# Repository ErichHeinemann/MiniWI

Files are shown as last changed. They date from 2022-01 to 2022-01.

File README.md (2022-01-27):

# MiniWI Fork with ESP32 and BLE ( Midi over Bluetooth )
MIDI woodwind controller

2022-01-27 E.Heinemann Use the folder for the MINI-WI-ESP32 Version to get a wireleess version which plays via Bluetooth BLE
Links to Youtube: https://www.youtube.com/embed/_GEmQJgfbyA

2016-04-17

This MIDI controller is running on an Arduino Pro Mini with Atmega328 16MHz/5V. It makes use of breakouts for analog pins A6 and A7, so it needs a Pro Mini version with these breakouts. The pressure sensor used for the project is the Freescale MPX5010GP. Fingering is reverse engineered from Akai EWI and note values are calculated from pressed keys. For details on this, read my guest post on the Gordophone blog. 

http://gordophone.blogspot.se/2016/04/guest-post-alternative-way-of-note.html

Details on the state machine approach for handling the events is also available on Gordon's blog where I borrowed it from. He's got a step-by-step how-to on DIY wind controllers that I highly recommend.

http://gordophone.blogspot.se/2013/01/a-series-basics-of-diy-wind-controllers.html

Hardware notes for connection of MIDI, pressure sensor, keys and joysticks are available in the MiniWI.ino file.

The MIDI routines and the MIDI connections are pretty standard, but I first found them on the midikits.net website, so I'll give Tom Scarff a mention here. Kept his nice MIDI pinout ASCII sketch thing and some comment style too. 

The controller is made to work well with synthesizers using wind controller patches from Patchman Music, with the breath data sent by CC #2 (Breath). For testing I’ve been using their wind controller soundbank for Roland JV-1010.

http://www.patchmanmusic.com

Or you can make your own patches optimized for breath control. Pointers for doing that can also be found on the Patchman website.

Questions and suggestions are welcome. Just send them to johan@helgo.net.

-Johan Berglund

2016-05-17

Variations:

MiniWI.ino is the original proof of concept breadboard version with regular switches.

MiniWI-lite.ino is a simplified version (no joysticks) for my guest post on the Gordophone blog.

MiniWI-cap.ino is the capacitive touch version implemented in my first playable prototype.

MiniWI-cap-pmt.ino is a modification of the touch version to feature portamento (glide) control and a separate potentiometer for setting base octave instead of using sideways motion of joystick to increase range. This reduces instantly playable range but increases the total range of the controller.

MiniVI-cap.ino is a not yet realized EVI version (Electronic Valve Instrument) based on the Akai EVI1000 and the Steiner MIDI EVI.

2016-05-22

I’ve added some pictures from my Instagram account. Check it out for more pictures from this and my other projects.

https://www.instagram.com/trasselfrisyr/

2016-05-30

Project profile for the MiniWI added on Hackaday.io

https://hackaday.io/project/11843-miniwi-woodwind-midi-controller

2016-06-03

Added optional Casio DH 2nd octave fingerings. Default disabled. Set #define casioMod 1 to set default enabled. Hold octave stick up at power on for manual selection of the setting that is not default.

2016-06-12

Added tested and working version of the new TeensieWI, a simplified version for USB MIDI using the built in capacitive touch sensing in the Teensy LC and breath sensing from the MPX5010GP. Small warning here: the breath sensor output is not limited and could reach values near 5V, while the analog input on the Teensy LC is 3.3V and not rated 5V safe. To reach these levels you’d have to blow really, really hard. If you need to feel safe, go with a Teensy 3.1 or 3.2 as they have 5V tolerant inputs. Only minor alterations needed in the code for use with Teensy 3.x (touch sensing on other pins, some as pads on the back).

2017-10-31

Improved the joystick version of the TeensieWI, now called T.WI, with breath response curves and some other stuff that can be configured at plug-in. Started making these for sale on Tindie. https://www.tindie.com/products/yoe/twi-a-teensy-based-usb-midi-woodwind-controller/

2022-01-03 E.Heinemann
#MINI WI ESP32
I am trying to build this Wind-Instrument but I changed the MCU from Aarduino to ESP32, still using a MPR121, MIDI via Blutooth, ADS115 as diffrential ADC for DP53-Pressuresensor

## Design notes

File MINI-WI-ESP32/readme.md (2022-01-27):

# MINI WI ESP32

I replaced the Arduino by an ESP32, still use an MPR121 via I2C ( GPIO-5 for SDA, GPIO-23 for SCL ) and an ADS1115 to get the differential pressure related voltage.
While COVID and the "Chip-Missing" - Pandemic, I bought 2 (bad or worse) DP53DP which are Differential Pressure Mesurement Sensors which need 2 ADC-inputs on the ADS1115.

Video ( german ) https://www.youtube.com/watch?v=_GEmQJgfbyA
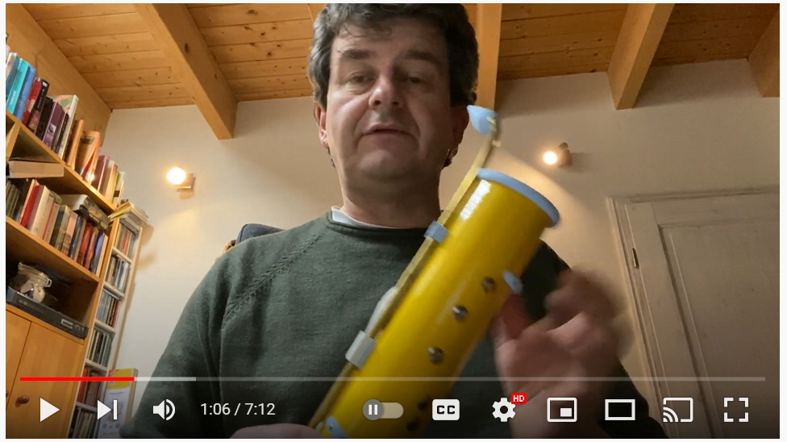
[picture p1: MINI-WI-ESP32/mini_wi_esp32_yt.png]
Youtube (https://www.youtube.com/watch?v=_GEmQJgfbyA "Mini WI Windinstrument on Youtube (german)")


As I had already bad experience with the ADC of the ESP, I tried to use a ADS115 and would add a MPU6050 later in the sketch to send MIDI-CC-Messages.

I don´t want to support a physical MIDI-Out, - to clunky wires and I did think of an internal battery but prefer an external USB-Powerbank which I could use for dirrent purposes ... I mainly play guitar, not MINI-WI. I did not implement the Joysticks in the code yet because I wanted to use the fingering of a normal recorder and I didn´t had Joysticks laying around. ( update - got Joystick )

Basically, I am a guitar-player and not a flute or sax-player. In school, we all had to learn to play the recorder and so, I tried to change the fingering to be the same like for a recorder.
I moved one touch-sensor to the back, used 2 sensors for the left hand pinky and 2 for the right pinky finger and one sensor (RH6) for the thumb of the right hand. 
Currently the right-hand thumb (RH6), switches to a lower octave.

For the body of the Mini-WI I used this material:
- an old inner cardboard role/pipe r=3.1cm by 40cm , 
- pimped it up with adhesive film ( one in gold and one in orange )
- thinnest brass-tube (1 meter ) from the hardwarestore ( around 3mm diameter )
- Silicon-Tube ( 50cm ) ( aquarium accessories )
- 12 cheap brass (looking) upholstery nails from hardwarestore ( 1cm diameter )
- thin isolated wire
- some sticky tape to manage the wires

I added a OpenSCAD-File which I used to create different 3D-printed parts like rings for the:
- fingerholes, - finally not used
- mouthpiece(s) , - a thin version and a wider version 
- top and bottom to cover the holes of the tube
- a holder to be able to mount the pressure-sensor from the outside

There was no need to cut the cardboard-role from top to bottom! 

Step 1:
Cut the cardboard-role to Your prefered length ( use Your hands to get a good length and don´t forget the reserved place/area for the ESP32 and other modules, hold it like a flute and find the length which looks good. )

Step 2: ( optional )
Wrap the adhesive film around it, leave top and bottom open

Step 3: 
Find the best places for the captive sensors. Hold the pipe like You would hold it for playing it as a flute or oboe etc.
Mark the position of Your fingers. Keep in mind, the pinkys will get 2 sensors, don´t spread Your pinky to much to reach out to the second hole.
As the sensors are captive sensors, there has to be enough space between the fingers and sensors.
Sensors for the left pinkys should be wider, for the right-hand pinkys it should be more narrow to be able to get both with the pinky at once.

Step 4:
Press the brass-Nails a bit into the cardboard-pipe to create simple holes.

Step 5:
Find a good position ( in my case on the right-side ) where You would like to inlay the pressure-sensor into the pipe.
Print out or build Your own holder for the pressure sensor. Take mesasurement and cur out an rectangle to push the sensor to the inside of the box. 
I have used a fresh sharp box cutter and a lot of respect.

Step 6:
print out the mouthpiece, bend the brass-tube to let it look like to upper part of a sax.
cut it  to let match the length of the mini-wi from mouthpiece down to the bottom! - full length!
Print out the Split-Box and some Pipe-Holders.

Step 7:
Do a second cut of the Brass-Pipe some centimeters below the pressure sensor where You have to install the Split-Box.
The Splitbox splits the air, comming from the mouthpieces and pressing it back upwords to the pressure-sensor which is facing downwards. 
.. any spit will flow downwards into the second brass pipe to the bottom.
Only Your feet will get wet after a long jam-session, - not Your fingers.
use 2 or more pipeholders to fix the brass-pipe onto the cardboard-pipe.

Step 8:
Solder thin isolated wire to the tip of the (12) brass-nails and loop the wire to the inside of the pipe. 
The wires should all fall down to the bottom of Your mini-wi.
Start with the highest Wire ( High c hole )

Step 9:
Print out the Bottom and later the Top to cover the Cardboard-Pipe.
I have tried to design two versions for the bottom. 
a) the USB faces straigt downwards ... Your have to lay down the instrument to the side if You pause Your jam-session
b) the USB faces backwards to You and You get a flat bottom, - Instrument could stand on the bottom.

Step 10:
use some Breadbaord/Stripboard which has a size of around 8 x 4cm to hold the modules:
MPR121, ADS1115 and ESP32 or only MPR121 and ADS1115 ( depends on the bottom-version a) or b) ) 
Use sockets for the modules or not, it is up to You.

Step 11:
Solder all modules ( depends on version of bottom ) to the Stripboards

Step 12:
Create the connection for VCC/VDD 3.3Volts, GND, SDA and SCL between all modules.
Connect the Wires from the brass-nails ( Touch Sensors ) from Bottom Down to the 12 Inputs 0 to 11 of the MPR121 module.

Step 13: 
Insert the MPX DP53DP (Pressure-Sensor ) via the silicon-tube to the Split-Box.
solder 4 wires to the DP52DP ( V+ goes to 3.3V or 5 Volts ...  I had measured very low voltages and decided to go to 5 Volts.
Out + / Out - have to be connected to the ADS1115 ADC0 and ADC1.
Check the documentation for YOUR pressure-seensor as I did not find a genral pinout of theem. they are different from modell to model!

Step 14:
Measure the connections to the ESP32 with a multimeter, - are there any shorts between SDA/SCL or +VDD and GND??
Check the Connection from the Touch-Sensors to the MPR121

Step 15:
Check the airpressure, - blow into the mouthpiece and check for any leakages. Air and spit should come out at the end of the brass-pipe at the bottom of the mini-wi.

Step 15:
Perhaps You have to install all the needed librarys or the Arduino IDE.
Upload the Core to the ESP32 ( perhaps You have to press "BOOT" to get it) 
I have used the Adafruit-Libraries for ADS1115 and the MPR121 and finally the "ESP32 BLE MIDI" - Library

Step 16:
Start an App on Your Smartphone which support MIDI BLE. 
Power up the Mini-WI, after the LED flashes stopps, blow into the moutpiece and press some brass-nails.

Step 17:
optimize it Your way, add Joysticks, more Touch-Sensors to the ESP32. 
Implement Your funktion when RH6 is pressed or Joysticks are moved.

There are a lot videos which explain how to connect a BLE - MIDI-Controller to Your Smartphone or PC.

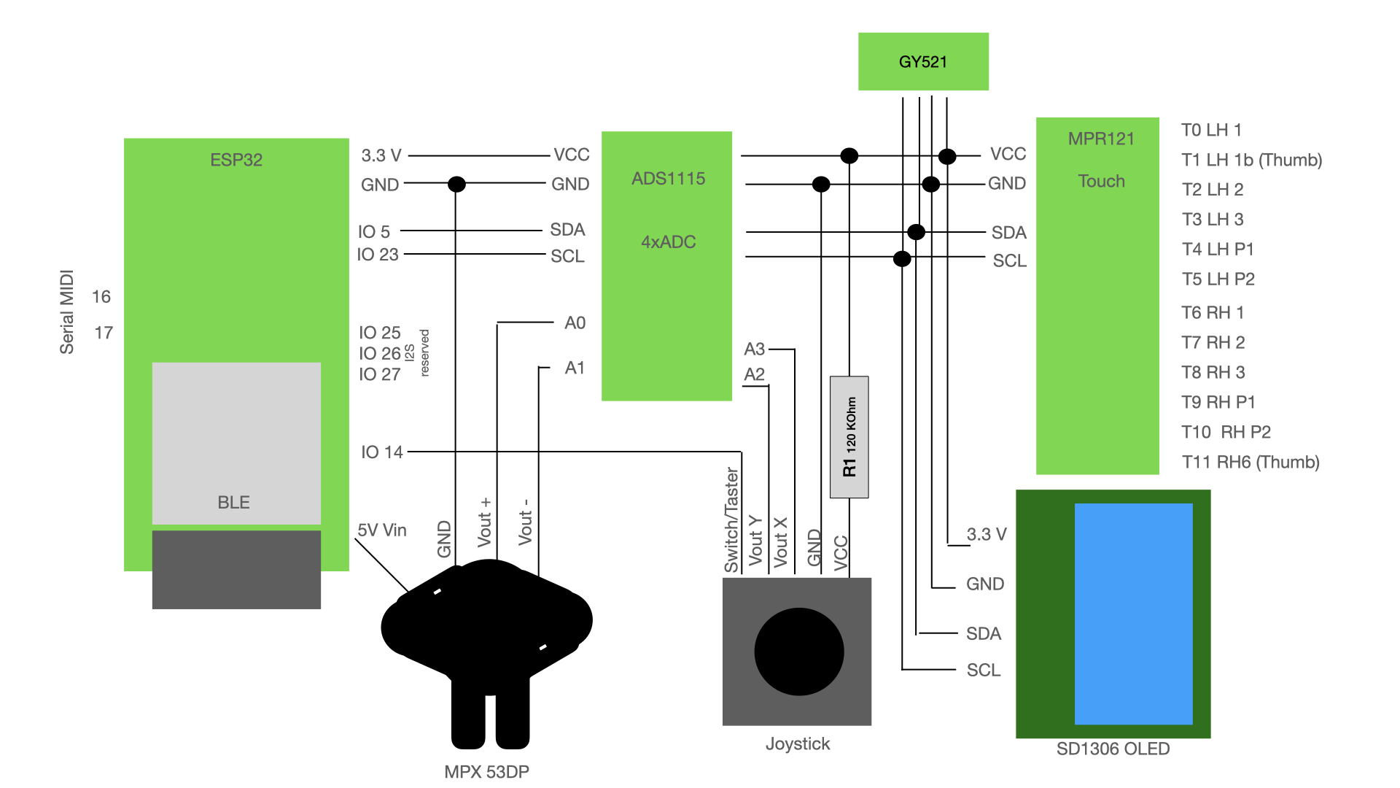
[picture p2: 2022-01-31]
MINI-WI-ESP32/MINI_WI_Schematic.001.png

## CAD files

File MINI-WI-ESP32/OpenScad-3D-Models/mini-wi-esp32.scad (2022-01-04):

// At the end, there are a lot of disabled statements
// active as amany as You need

// OpenSource GPL 

// E.Heinemann 2022

radPipe = 50; // 10cm
radRing = 6;


$fs = 0.15;
$fn = 50;
/*
color ("Red") rotate([180,0,0])linear_extrude(height=2) { scale([0.1,0.1])
import(file = "milbesos.svg", center = true, dpi = 96);
}
rotate([0,0,0])linear_extrude(height=5,convexity=2) { scale([0.45,0.45])
import(file = "milbesos.svg", center = false, dpi = 96);
}
*/

module roundedcube(size = [1, 1, 1], center = false, radius = 0.5, apply_to = "all") {
	// If single value, convert to [x, y, z] vector
	size = (size[0] == undef) ? [size, size, size] : size;

	translate_min = radius;
	translate_xmax = size[0] - radius;
	translate_ymax = size[1] - radius;
	translate_zmax = size[2] - radius;

	diameter = radius * 2;

	obj_translate = (center == false) ?
		[0, 0, 0] : [
			-(size[0] / 2),
			-(size[1] / 2),
			-(size[2] / 2)
		];

	translate(v = obj_translate) {
		hull() {
			for (translate_x = [translate_min, translate_xmax]) {
				x_at = (translate_x == translate_min) ? "min" : "max";
				for (translate_y = [translate_min, translate_ymax]) {
					y_at = (translate_y == translate_min) ? "min" : "max";
					for (translate_z = [translate_min, translate_zmax]) {
						z_at = (translate_z == translate_min) ? "min" : "max";

						translate(v = [translate_x, translate_y, translate_z])
						if (
							(apply_to == "all") ||
							(apply_to == "xmin" && x_at == "min") || (apply_to == "xmax" && x_at == "max") ||
							(apply_to == "ymin" && y_at == "min") || (apply_to == "ymax" && y_at == "max") ||
							(apply_to == "zmin" && z_at == "min") || (apply_to == "zmax" && z_at == "max")
						) {
							sphere(r = radius);
						} else {
							rotate = 
								(apply_to == "xmin" || apply_to == "xmax" || apply_to == "x") ? [0, 90, 0] : (
								(apply_to == "ymin" || apply_to == "ymax" || apply_to == "y") ? [90, 90, 0] :
								[0, 0, 0]
							);
							rotate(a = rotate)
							cylinder(h = diameter, r = radius, center = true);
						}
					}
				}
			}
		}
	}
}

module ring(
        h=1,
        od = 10,
        id = 5,
        de = 0.1
        ) 
{
    difference() {
        cylinder(h=h, r=od/2);
        translate([0, 0, -de])
            cylinder(h=h+2*de, r=id/2);
    }
}


// ring(2, 16, 12, 0.1 );

module torus2(r1, r2)
{
rotate_extrude() translate([r1,0,0]) circle(r2);
}

module oval_torus(inner_radius, thickness=[0, 0])
{
rotate_extrude() translate([inner_radius+thickness[0]/2,0,0]) ellipse(width=thickness[0], height=thickness[1]);
}


module fingerhole( rFinger = 8, rPipe = 50 ){
    difference(){
      union(){  
        torus2( rFinger, 1.1 );
        difference(){  
            color([0,1,0]) rotate([0,-90,0]) translate([ -(rPipe/2 + rFinger*1),0,0 ]) torus2(rPipe/2,  rFinger *1.3 );
             cylinder( rFinger*2.5, rFinger, rFinger, center=true);
        }
      }    
      union(){
        //translate ([0,0,0.5 ]) ring(1, (rFinger*2)-2, (rFinger*2)-4, 0.1 );
        translate ([0,0,0.5 ]) cylinder(1, 5, 5 );
        rotate([0,-90,0]) translate([ -rPipe,0,-0 ]) color([1,0,0]) cylinder( rFinger*4, rPipe, rPipe, center=true);
          
      }
    }
}


module fingerpinch( rFinger = 8, lPinch=16, wPinch=8, r1=30, r2=30, rPipe = 50 ){
    
    difference(){
      union(){  
        // translate([  0, lPinch/3/2+rFinger ,0 ]) roundedcube([ wPinch, lPinch /3 , 4 ], center=true, 0.5);  
          difference(){
              union(){
                          torus2( rFinger, 2 );
        rotate( [0,0,-r1] ) translate([  0, lPinch/2+rFinger ,0 ]) 
              roundedcube([ wPinch, lPinch, 4 ], center=true, 0.5);
              }      
        rotate( [0,0,-r1] ) translate([  0, lPinch/2+rFinger ,0 ]) 
              translate([ 0, 3 ,2 ]) cube([ 2, lPinch*1.5, 2 ], center=true);  
         }

        difference(){  
            color([0,1,0]) rotate([0,-90,0]) translate([ -(rPipe/2+ rFinger),2,-0 ]) torus2(rPipe/2,  rFinger *1.3 );
             cylinder( rFinger*2.5, rFinger, rFinger, center=true);
        }
      }    
      union(){
  
          
        translate ([0,0,0.5 ]) ring(1, (rFinger*2)-2, (rFinger*2)-4, 0.1 );
        rotate([0,-90,0]) translate([ -rPipe,0,-0 ]) color([1,0,0]) cylinder( rFinger*4, rPipe, rPipe, center=true);
          
      }
    }
}

module dualfingerhole( rFinger1 = 8, rFinger2=7, rPipe = 50 ){
    difference(){
      union(){  
        translate ([rFinger1+0.5,0,0 ])  torus2( rFinger1, 2 );
        translate ([-rFinger2-0.5,0,0 ])  torus2( rFinger2, 2 );
          
        difference(){  
           color([0,1,1]) rotate([0,-90,0]) translate([ -(rPipe/2+ rFinger1),2,-0 ]) torus2(rPipe/2,  rFinger1 *1.3 );
            union(){
             translate ([rFinger1+0.5,0,0 ]) cylinder( rFinger1*2.5, rFinger1, rFinger1, center=true);
             translate ([-rFinger2-0.5,0,0 ])cylinder( rFinger2*2.5, rFinger2, rFinger2, center=true);
        }
        }
      }    
      union(){
        translate ([rFinger1+0.5,0,0.5 ]) ring(1, (rFinger1*2)-2, (rFinger1*2)-4, 0.1 );
        translate ([-rFinger2-0.5,0,0.5 ]) ring(1, (rFinger2*2)-2, (rFinger2*2)-4, 0.1 );

        rotate([0,-90,0]) translate([ -rPipe,0,-0 ]) color([1,1,0]) cylinder( (rFinger1+rFinger2)*4, rPipe, rPipe, center=true);
          
      }
    }
}


module dualsidefingerhole( rFinger1 = 8, rFinger2=7, rotFinger1=1, rotFinger2=5, rPipe = 50 ){
    difference(){
      union(){  
        rotate([-rotFinger1,0,0]) translate ([0,rFinger1+1,0 ])  torus2( rFinger1, 2 );
        rotate([rotFinger2,0,0]) translate ([0,-rFinger2,0 ])  torus2( rFinger2, 2 );
          
        difference(){  
            color([0,1,1]) rotate([0,-90,0]) translate([ -(rPipe/2+ rFinger1),2,-0 ]) torus2(rPipe/2,  rFinger1 *1.3 );
            union(){
             rotate([- rotFinger1,0,0]) translate ([0, rFinger1+1,0 ]) cylinder( rFinger1*2.5, rFinger1, rFinger1, center=true);
             rotate([rotFinger2,0,0])  translate ([0,-rFinger2,0 ])cylinder( rFinger2*2.5, rFinger2, rFinger2, center=true);
        }
        }
      }    
      union(){
       rotate([- rotFinger1,0,0]) translate ( [0,rFinger1+1,0.5 ]) ring( 1, (rFinger1*2)-2, (rFinger1*2)-4, 0.1 );
       rotate([rotFinger2,0,0]) translate ([0,-rFinger2,0.5 ]) ring( 1, (rFinger2*2)-2, (rFinger2*2)-4, 0.1 );

        rotate([0,-90,0]) translate([ -rPipe,0,-0 ]) color([1,1,0]) cylinder( (rFinger1+rFinger2)*4, rPipe, rPipe, center=true);
          
      }
    }
}

module mouthpiece( w1=8, w2=10, h1=50 , h2=8, dr=3 ){
    // dr = durchmesser der Tube 
  difference(){
    hull(){
      translate([0,0,h1/10])cylinder( w1,w2,w2 ); 
      color([1,1,0]) translate([0,- w1/3,0])cylinder( 10,dr+1,dr+1 );   
      //translate([0,0,h1/2 + 2]) cube( [w2,w2,h1/2] , center=true); 
      translate([0,-w2/4,h1/2 + 2]) roundedcube( [w2,w2/2,h1] , center=true , 0.5); 
               
    }
    
    union(){
   rotate([0,-90,0]) translate([ h1,h1,-0 ]) color([1,1,0]) cylinder( (w1+w2), h1, h1, center=true );
        hull(){
       translate([0,-w2/4,h1])cube( [w2/1.5,w2/4,h1/2] , center=true );        
     // the hole for the pipe to the body
      color([1,1,0]) translate([0,- w1/3,0])cylinder( h1/2,dr,dr );   
        }
        
    }
  }
}

module mouthpieceWide( w1=8, w2=18, h1=50 , h2=8, dr=3 ){
    // dr = durchmesser der Tube 
  difference(){
    hull(){
      translate([0,0,h1/10])cylinder( w1,w2/1.8,w2/1.8 ); 
      color([1,1,0]) translate([0,- w1/3,0])cylinder( 10,dr+1,dr+1 );   
      //translate([0,0,h1/2 + 2]) cube( [w2,w2,h1/2] , center=true); 
      translate([0,-w2/4,h1/2 + 10]) roundedcube( [w2*1.1,w2/5,h1-5] , center=true , 0.5); 
               
    }
    
    union(){
        
        // Testschnitt: translate([0,-10,-5]) cube([100,100,100]);
        rotate([0,-90,0]) translate([ h1-4,h1+1.5,-0 ]) cylinder( (w1+w2), h1+1, h1+1, center=true );
        hull(){
            translate([0,-w2/4,h1])cube( [w2/1.5,w2/16,h1/2] , center=true );        
            // the hole for the pipe to the body
            color([1,1,0]) translate([0,- w1/3,0])cylinder( h1/2,dr,dr );   
        }
        
    }
  }
}


module pipeflansch( dr=3.55, rPipe=29.5 ){
    difference(){
      union(){  
        //#torus2( dr, 2 );
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

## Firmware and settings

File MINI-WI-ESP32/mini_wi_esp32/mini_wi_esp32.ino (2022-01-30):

#include <Arduino.h>

// #define MIDI5Pin

// ESP32_BLE_MIDI https://github.com/max22-/ESP32-BLE-MIDI
#define ESP32_BLE_MIDI

#ifdef ESP32_BLE_MIDI
#include <BLEMidi.h>
#endif

// #define PitchbendTouch
#define PitchbendAnalog

// #define ModulationGyro
#define ModulationAnalog
#define ModulationPortamentoCombi


/*
 * 
 * // https://github.com/lathoub/Arduino-BLE-MIDI
#include <BLEMIDI_Transport.h>

// #include <hardware/BLEMIDI_ESP32_NimBLE.h>
#include <hardware/BLEMIDI_ESP32.h>
// #include <hardware/BLEMIDI_nRF52.h>
// #include <hardware/BLEMIDI_ArduinoBLE.h>

// BLEMIDI_CREATE_DEFAULT_INSTANCE()
BLEMIDI_CREATE_INSTANCE( "MIDI MINI WI", MIDI )
// 9c:9c:1f:e2:19:d2
*/

unsigned long t0 = millis();
bool isConnected = false;

uint8_t modus = 0; // 0 = Play-Mode 1= Menu

// GPIO 14, Touch6 as extra Touchpin used directly on ESP32
uint8_t touchpin = 14; // touchpin_val= touchRead( touchpin ); 
uint16_t touchPin_Value=0; // Value of readed touchpin
uint16_t touchPin_Value_Max = 70; // has to be evaluated
uint16_t touchPin_last_Value=0;
uint8_t touchPin_Value_midi=0;
uint8_t velocity_min = 50;
// #include "FS.h"
// #include <LITTLEFS.h>

#include <WiFi.h>

// #include <MIDI.h>
#define NORM127MUL  0.007874f

// #define MIDIRX_PIN 16
// #define MIDITX_PIN 17

  uint16_t touchValue = 0;
  uint16_t lastTouchValue = 0;

// struct Serial2MIDISettings : public midi::DefaultSettings{
//   static const long BaudRate = 31250;
//   static const int8_t RxPin  = MIDIRX_PIN;
//   static const int8_t TxPin  = MIDITX_PIN; // LED-Pin
// };

// HardwareSerial MIDISerial(2);
// MIDI_CREATE_CUSTOM_INSTANCE( HardwareSerial, MIDISerial, MIDI, Serial2MIDISettings );


//I2C
#include <SPI.h>
#include <Wire.h>

// Display
// #include <Adafruit_GFX.h>
// #include <Adafruit_SSD1306.h>

// MPR121
#include <Adafruit_MPR121.h>

// ADS1115
#include <Adafruit_ADS1X15.h>

// Adafruit_ADS1115 ads;  /* Use this for the 16-bit version */
Adafruit_ADS1015 ads;     /* Use this for the 12-bit version */
#define ADC_ADDRESS 0x48


// Lines for the SD1306 Display
char *d_line0="Mini WI"; // Titel
char *d_line1=" ";  // Mode
char *d_line2=" ";        // Param 1     
char *d_line3=" ";        // Param 2  
char *d_line4=" ";        // Note  
char *d_line5=" ";        // Breath  
   
byte octave = 0;
byte noteInOctave = 1;

// Accelration-Sensor / Tiltsensor for additional CC-Messages !!
#include <Adafruit_MPU6050.h>
#include <Adafruit_Sensor.h>
Adafruit_MPU6050 mpu;
int gyro_x;
int gyro_y;
int gyro_z;
uint16_t gyro_total =0; // Summ of all movements forward or backwards
uint16_t gyro_total_old =0;
uint16_t gyro_total_max = 127; // The maximum Value of chaking the instrument detected by the Gyro-Sensor UMP6050
byte gyro_total_midi=0;
int calib_gyro_x;
int calib_gyro_y;
int calib_gyro_z;

int old_gyro_x;
int old_gyro_y;
int old_gyro_z;

bool display_changed = false; // if this is true, the display will get a refresh

// #define DEBUGGING  1

uint16_t prescaler_gyro_counter =0;
uint16_t prescaler_gyro_th = 60;

uint16_t prescaler_display_counter =0;
uint16_t prescaler_display_th = 200;

char * noteNames[] = {"C", "C#", "D", "D#", "E", "F", "F#", "G", "G#", "A", "Bb", "H"};
 
// Source:
// https://hackaday.io/project/11843-miniwi-woodwind-midi-controller

// Gyro and Acceleration-Sensor?? MPU-6050 / GY571 ??

/*
NAME:                 MiniWI Cap Touch and Portamento ver.
WRITTEN BY:           JOHAN BERGLUND
CREDITS:              State machine from the Gordophone blog by GORDON GOOD
DATE:                 2016-06-01
FILE SAVED AS:        MiniWI-cap-pmt.ino
FOR:                  Arduino Pro Mini, ATmega328, version with breakouts for A6 and A7
CLOCK:                16.00 MHz CRYSTAL                                        
PROGRAMME FUNCTION:   Wind Controller with EWI style key setup (reduced) with optional Casio DH addition, 
                      Freescale MPX5010GP breath sensor, PS2 style thumb joysticks 
                      for octave selection and pb/mod control, capacitive touch keys, output to 5-pin DIN MIDI 

HARDWARE NOTES for MINI-WI (Arduino):
* For the MIDI connection, attach a MIDI out Female 180 Degree 5-Pin DIN socket to Arduino.
* Socket is seen from solder tags at rear.
* DIN-5 pinout is:                                         _______ 
*    pin 2 - GND                                          /       \
*    pin 4 - 220 ohm resistor to +5V                     | 1     3 |  MIDI jack
*    pin 5 - Arduino Pin 1 (TX) via a 220 ohm resistor   |  4   5  |
*    all other pins - unconnected                         \___2___/
*
* Left hand thumb joystick controls octaves.
* Up/down axis is connected to Arduino pin A6.
* 
*       ^
*     < o >
*       v
*      -1
* 
* A potentiometer connected to Arduino pin A7 sets the base octave -2 to +2 from startnote octave.
*
* Right hand thumb joystick controls pitch bend and modulation.
* Pitch bend and modulation are connected to Arduino pins A0 and A1,
* on DIP rows.
* 
*     PB up
*       ^
* Mod < o > Mod
*       v
*     PB dn
*     
* A potentiometer controls portamento speed setting.
* It is connected to Arduino pin A2.  
*     
* The Freescale MPX5010GP pressure sensor output (V OUT) is connected to Arduino pin A3.
* 
* 1: V OUT (pin with indent)
* 2: GND
* 3: VCC (to 5V)    
* 4: n/c
* 5: n/c
* 6: n/c
*     
*     
* MII-WI ESP32    
* Autor: E.Heinemann
* Code is based on the MINI-WI - Project from JOHAN BERGLUND
* 
* The cheapere Freescale MPX53DP pressure is not thee best option, because it uses 2 Pins on the ADS1115, but it was the only available one 
* 
* 1: GND (pin with indent)
* 2: +Vout to ADC0 ADS1115 Pin A0 
* 
* * 3: +VSS  to 5Volts
* 4: -Vout to ADC1 ADS1115 PIN A1
* 5: n/c
* 6: n/c
* 
* Midi panic is not implemented yet ... on pin 11 and 12 (internal pullup, both pins low sends all notes off)
* GPIO 25, 26,27 are reserverd for I2S in a later version which includes a duophonee Synth-Engine
* 
* SDA / SCL are provided by 
* 
*/

//_______________________________________________________________________________________________ DECLARATIONS

int breath_Thr = 120;    // Set threshold level before switching ON
#define  ON_Delay   12   // Set Delay after ON threshold before velocity is checked (wait for tounging peak)
int breath_max=135;  // Blowing as hard as you can // 5 Volt to the MPX DP53DP

uint16_t modsLo_Thr=480;  // Low threshold for mod stick center
uint16_t modsHi_Thr=510;  // High threshold for mod stick center

uint16_t pbsLo_Thr=480;  // Low threshold for mod stick center
uint16_t pbsHi_Thr=510;  // High threshold for mod stick center

uint16_t octsLo_Thr=480;  // Low threshold for octave stick center
uint16_t octsHi_Thr=510;  // High threshold for octave stick center

/*
#define octsLo1_Thr 409  // Low threshold for octave select pot
#define octsHi1_Thr 613  // High threshold for octave select pot
#define octsLo2_Thr 205  // Low threshold 2 for octave select pot
#define octsHi2_Thr 818  // High threshold 2 for octave select pot
*/

#define PB_sens 8191 // 4095    // Pitch Bend sensitivity 0 to 8191 where 8191 is full pb range

// The three states of our state machine

// No note is sounding
#define NOTE_OFF 1

// We've observed a transition from below to above the
// threshold value. We wait a while to see how fast the
// breath velocity is increasing
#define RISE_WAIT 2

// A note is sounding
#define NOTE_ON 3

// Send CC data no more than every CC_INTERVAL
// milliseconds
#define CC_INTERVAL 50 

//variables setup

int state;                         // The state of the state machine
unsigned long ccSendTime = 0L;     // The last time we sent CC values
unsigned long breath_on_time = 0L; // Time when breath sensor value went over the ON threshold
int16_t initial_breath_value;          // The breath value at the time we observed the transition

int16_t xOctaves;
int16_t yOctaves;

int potPinModulation = 34; // GPIO-PIn on ESP32 for Modulation Values from 0 to 4095!
  
long lastDebounceTime = 0;         // The last time the fingering was changed
long debounceDelay = 30;           // The debounce time; increase if the output flickers
int lastFingering = 0;             // Keep the last fingering value for debouncing

uint8_t MIDIchannel=0;                // MIDI channel 1

int modLevel;
int oldmod=0;

int16_t pitchBendAnalog;
int oldpb=8192;

int16_t portLevel;
int oldport=-1;

int16_t breathLevel=0;   // breath level (smoothed) not mapped to CC value

int16_t pressureSensor;  // pressure data from breath sensor, for midi breath cc and breath threshold checks
byte velocity;       // remapped midi velocity from breath sensor

int fingeredNote;    // note calculated from fingering (switches) and octave joystick position
byte activeNote;     // note playing
byte startNote=74;   // set startNote to D (change this value in steps of 12 to start in other octaves)

byte midistatus=0;
byte x;
byte LedPin = 2;    // select the pin for the LED, 2 on ESP32, 13 on Arduino

Adafruit_MPR121 touchSensor = Adafruit_MPR121(); // This is the 12-input touch sensor

     // Key variables, TRUE (1) for pressed, FALSE (0) for not pressed
byte LH1;   // Left Hand key 1 (pitch change -2) 
byte LHb;   // Daumen auf der Rückseite wie bei Blöckflöte
            // Left Hand bis key (pitch change -1 unless both LH1 and LH2 are pressed)
byte LH2;   // Left Hand key 2  (with LH1 also pressed pitch change is -2, otherwise -1)
byte LH3;   // Left Hand key 3 (pitch change -2)

byte LHp1;  // Left Hand pinky key 1 (pitch change -1)
byte LHp2;  // Left Hand pinky key 2 (pitch change +1)

byte RH1;   // Right Hand key 1 (with LH3 also pressed pitch change is -2, otherwise -1)
byte RH2;   // Right Hand key 2 (pitch change -1)
byte RH3;   // Right Hand key 3 (pitch change -2)
byte RHp1=0;// Right Hand pinky key 1 (pitch change -1) 
byte RHp2;  // Right Hand pinky key 2 (pitch change -1)

byte RH6;  // Right Hand Thumb or pinky key 3, Pitch - 12 to get a lower register

byte OCTup=0; // Octave switch key (pitch change +12) --- Not used in this version 
byte OCTdn=0; // Octave switch key (pitch change -12) --- Not used in this version

byte PortK;   // Portamento momentary on switch
byte oldportk;

int joyOct; // Octave shifting by joystick or potentiometer


// ADS1115 - Integration
// #include <Adafruit_ADS1X15.h>
// Adafruit_ADS1115 ads;  // Use this for the 16-bit version

// remove resistors 70 and 68  on AI Thinker Audio 2.2 - Board to free up Pin 5 and Pin 23!

#define SDA2 5
#define SCL2 23

TwoWire I2Ctwo = TwoWire(0);

#define ADC_ADDRESS 0x48

//  4 Analog-Inputs:
//   A0 = breath - Differential
//   A1 = breath - Differential
//   A2 = Joystick Y
//   A3 = Joystick X

int16_t adc0, adc1, adc2, adc3;
int16_t adc0_1, adc1_1, adc2_1, adc3_1;

uint16_t ads_prescaler = 0; 
uint16_t patch_edit_prescaler = 0; // Wait seconds after loading to sync the values

void onNoteOnESP32( uint8_t channel, uint8_t note, uint8_t velocity, uint16_t timestamp ){
#ifdef DEBUGGING
   Serial.printf("Received note on : channel %d, note %d, velocity %d (timestamp %dms)\n", channel, note, velocity, timestamp);
#endif
}

void onNoteOffESP32(uint8_t channel, uint8_t note, uint8_t velocity, uint16_t timestamp ){ 
#ifdef DEBUGGING   
   Serial.printf("Received note off : channel %d, note %d, velocity %d (timestamp %dms)\n", channel, note, velocity, timestamp);  
#endif
}

void onControlChangeESP32(uint8_t channel, uint8_t controller, uint8_t value, uint16_t timestamp){
#ifdef DEBUGGING
  Serial.printf("Received control change : channel %d, controller %d, value %d (timestamp %dms)\n", channel, controller, value, timestamp);
#endif  
}
void onConnectedESP32( ){
  isConnected = true;
#ifdef DEBUGGING
  Serial.println("Connected"); // (timestamp %dms)\n", timestamp);
#endif
}
void onDisconnectedESP32(  ){
  isConnected = false;
#ifdef DEBUGGING
  Serial.println("Disconnected");
#endif
}



//_______________________________________________________________________________________________ SETUP

void setup() {

// #ifdef MIDI5Pin
//   Serial.begin(31250);  // start serial with midi baudrate 31250
// #else
  Serial.begin(115200);  // start serial with midi baudrate 31250
  Serial.flush();
// #endif
  // pinMode( MIDIRX_PIN , INPUT_PULLUP);  // GPIO16 
  // MIDISerial.begin( 31250, SERIAL_8N1, MIDIRX_PIN, MIDITX_PIN ); // midi port
  // MIDI_setup();

#if 0
    setup_wifi();
#else
//    WiFi.mode(WIFI_OFF);
#endif

  pinMode( LedPin, OUTPUT );   // declare the LED's pin as output

#ifdef DEBUGGING  
  Serial.printf("BLE-Setup\n");
  Serial.println("Initializing bluetooth");
#endif 
#ifdef ESP32_BLE_MIDI
  // BLE-MIDI
  BLEMidiServer.begin("MIDI MINI WI");
  BLEMidiServer.setNoteOnCallback( onNoteOnESP32 );
  BLEMidiServer.setNoteOffCallback( onNoteOffESP32 );
  BLEMidiServer.setControlChangeCallback( onControlChangeESP32 );
  BLEMidiServer.setOnConnectCallback( onConnectedESP32 );
  BLEMidiServer.setOnDisconnectCallback( onDisconnectedESP32 );  
  // BLEMidiServer.enableDebugging();
#endif  

#ifdef BLE_MIDI
  MIDI.begin();  
  BLEMIDI.setHandleConnected([](){
    Serial.println("Connected");
    isConnected = true;
    digitalWrite( LedPin, HIGH );
  });

  BLEMIDI.setHandleDisconnected([]() {
    Serial.println("Disconnected");
    isConnected = false;
    digitalWrite(LedPin, LOW);
  });

  MIDI.setHandleNoteOn([](byte channel, byte note, byte velocity) {
    digitalWrite(LedPin, LOW);
  });
  MIDI.setHandleNoteOff([](byte channel, byte note, byte velocity) {
    digitalWrite(LedPin, HIGH);
  });
#endif    

  state = NOTE_OFF;  // initialize state machine

#ifdef DEBUGGING
  Serial.printf("PinMode-Setup\n");
#endif

  // void Core0TaskSetup(){
  // I2C
  Serial.printf("I2C-Setup\n");
  
  pinMode( SDA2, INPUT_PULLUP ); 
  pinMode( SCL2, INPUT_PULLUP ); 
  I2Ctwo.begin( SDA2, SCL2, 50000 ); // SDA2 pin 0, SCL2 pin 5, works with 50.000 Hz if pinned to other Core0

  // Set up touch sensor
  // begin(uint8_t i2caddr = MPR121_I2CADDR_DEFAULT, TwoWire *theWire = &Wire,
  //           uint8_t touchThreshold = MPR121_TOUCH_THRESHOLD_DEFAULT,
  //           uint8_t releaseThreshold = MPR121_RELEASE_THRESHOLD_DEFAULT);
  Serial.printf("MPR121-Setup\n");
  if (!touchSensor.begin( 0x5A, &I2Ctwo )) {
    while (1);  // Touch sensor initialization failed - stop doing stuff
    Serial.printf("MPR121-Setup failed\n");
  }

  mpu6050_setup();
  
  display_setup();
  Serial.printf("LED-Blink\n");
  for (x=1; x<=4; x++){  // Do the flashy-flashy to say we are up and running
    digitalWrite( LedPin, HIGH );
    delay(300);
    digitalWrite( LedPin, LOW );
    delay(300);
  }

#ifdef DEBUGGING
  Serial.printf("ADS1115 Setup\n");
#endif
  // ADS1115

#ifdef DEBUGGING
  Serial.println("Getting single-ended readings from AIN0..3");
  Serial.println("ADC Range: +/- 6.144V (1 bit = 3mV/ADS1015, 0.1875mV/ADS1115)");
#endif
  ads.begin( ADC_ADDRESS,  &I2Ctwo   );
#ifdef DEBUGGING
  Serial.println("ADS1115 started");

  Serial.printf("Pressure Calibration\n");
#endif  
  pressure_calibration();
#ifdef PitchbendAnalog
  ads1115_calibration_pitchbend();
#endif
#ifdef ModulationAnalog
  ads1115_calibration_modulation();
#endif

}

//
// calibration of Pressure Sensor while "no" pressure
//
void pressure_calibration(){
  ads.setGain( GAIN_SIXTEEN ); // GAIN_FOUR (for an input range of +/-1.024V) / GAIN_EIGHT (for an input range of +/-0.512V)
 // Start Calibration
  breath_Thr = ads.readADC_Differential_0_1();
    digitalWrite( LedPin, HIGH );
    delay(300);
    digitalWrite( LedPin, LOW );
    delay(300);
  breath_Thr += ads.readADC_Differential_0_1();
    digitalWrite( LedPin, HIGH );
    delay(300);
    digitalWrite( LedPin, LOW );
    delay(300);
  breath_Thr += ads.readADC_Differential_0_1();
    digitalWrite( LedPin, HIGH );
    delay(300);
    digitalWrite( LedPin, LOW );
    delay(300);
  breath_Thr += ads.readADC_Differential_0_1();
  breath_Thr = ( breath_Thr / 4 ) + 5; // +2 or +3 check if there are too many Sounds which don´t stop
  // Display the result of the calibration


  
}
//_______________________________________________________________________________________________ MAIN LOOP

void loop() {

#ifdef BLE_MIDI
   MIDI.read();
#endif


prescaler_gyro_counter +=1;
if( prescaler_gyro_counter > prescaler_gyro_th ){
  mpu6050_read();  
  prescaler_gyro_counter = 0;
}

prescaler_display_counter +=1;
if( display_changed== true || prescaler_display_counter > prescaler_display_th ){
  update_display();  
  prescaler_display_counter =0;
  display_changed = false;
}

// if(BLEMidiServer.isConnected()) { 

  // if both joystick buttons are pressed, send all notes off
  //if((digitalRead(11) == 0) && (digitalRead(12) == 0)){
  //  midiPanic();
  //}

  // read all analog signals from ADS1115
  // pressureSensor = analogRead(A3); // Get the pressure sensor reading from analog pin A3
  // pressureSensor = ads.readADC_SingleEnded(0);
  
  pressureSensor = ads.readADC_Differential_0_1();
  
   // Serial.print( "Breath: " );   
   // Serial.print( pressureSensor );
   // Serial.print( " > " );   
   // Serial.println(   ON_Thr );

  if( state == NOTE_OFF ){
    if( pressureSensor > breath_Thr ){
      // Value has risen above threshold. Move to the ON_Delay
      // state. Record time and initial breath value.
#ifdef DEBUGGING
      Serial.print( pressureSensor );
      Serial.print( " > " );   
      Serial.println(   breath_Thr );
#endif      
      breath_on_time = millis();
      initial_breath_value = pressureSensor;
      state = RISE_WAIT;  // Go to next state
      if( pressureSensor > breath_max ){ breath_max = pressureSensor ;}
      display_changed= true;
    }
  }else if( state == RISE_WAIT ){
    if( pressureSensor > breath_Thr ){
      // Has enough time passed for us to collect our second
      // sample?
      if( millis() - breath_on_time > ON_Delay ){
        if( pressureSensor > breath_max ){ breath_max = pressureSensor ;}
#ifdef DEBUGGING
        Serial.print( pressureSensor );
        Serial.print( " > " );   
        Serial.println(   breath_Thr );
#endif
        // Yes, so calculate MIDI note and velocity, then send a note on event
        readSwitches();
        //readOctaves();
        oldportk=2; // Set oldportk to a value other than 1 or 0 to make sure it always sends the data for new notes
        //portamento();
        // We should be at tonguing peak, so set velocity based on current pressureSensor value        
        // If initial value is greater than value after delay, go with initial value, constrain input to keep mapped output within 7 to 127
        velocity = map( constrain( max(pressureSensor,initial_breath_value), breath_Thr, breath_max ), breath_Thr, breath_max, velocity_min, 127 );
        breathLevel=constrain( max(pressureSensor, initial_breath_value), breath_Thr, breath_max );
 #ifdef MIDI5Pin       
        midiSend((0x90 | MIDIchannel), fingeredNote, velocity); // send Note On message for new note
#endif
#ifdef ESP32_BLE_MIDI
        BLEMidiServer.noteOn(  MIDIchannel, fingeredNote, velocity  );
#endif
#ifdef BLE_MIDI
        MIDI.sendNoteOn( fingeredNote, velocity,  MIDIchannel );
#endif        
        activeNote=fingeredNote;
        state = NOTE_ON;
        display_changed= true;        
      }
    }else{
      // Value fell below threshold before ON_Delay passed. Return to
      // NOTE_OFF state (e.g. we're ignoring a short blip of breath)
      state = NOTE_OFF;
      display_changed= true;   
    }
  }else if( state == NOTE_ON ){
    if( pressureSensor < breath_Thr){
      // Value has fallen below threshold - turn the note off
#ifdef MIDI5pin
      midiSend((0x80 | MIDIchannel), activeNote, 0); //  send Note Off message 
#endif
#ifdef ESP32_BLE_MIDI
      BLEMidiServer.noteOff(  MIDIchannel, activeNote, 0  );
#endif
#ifdef BLE_MIDI
      MIDI.sendNoteOff(  activeNote, 0,  MIDIchannel );
#endif      
      breathLevel=0;
      state = NOTE_OFF;
      display_changed= true;        
    }else{
      // Is it time to send more CC data?
      if( millis() - ccSendTime > CC_INTERVAL ){
         // deal with Breath, Pitch Bend and Modulation
         breath();
         // 2022 Modulation und Pitchbend deaktiviert
         pitch_bend();
         modulation();
         ccSendTime = millis();
      }
      readSwitches();
      // readOctaves();
      if( fingeredNote != lastFingering ){ //
        // reset the debouncing timer
        lastDebounceTime = millis();
      }
      if(( millis() - lastDebounceTime) > debounceDelay ){
      // whatever the reading is at, it's been there for longer
      // than the debounce delay, so take it as the actual current state
        if( fingeredNote != activeNote ){
          // Player has moved to a new fingering while still blowing.
          // Send a note off for the current note and a note on for the new note.
          // portamento();        
          velocity = map(constrain( pressureSensor, breath_Thr, breath_max ), breath_Thr, breath_max, velocity_min, 127 ); // set new velocity value based on current pressure sensor level
#ifdef MIDI5Pin
          midiSend(( 0x90 | MIDIchannel), fingeredNote, velocity ); // send Note On message for new note
#endif          
#ifdef ESP32_BLE_MIDI
          BLEMidiServer.noteOn(  MIDIchannel, fingeredNote, velocity  );
#endif
#ifdef BLE_MIDI
          MIDI.sendNoteOn(  fingeredNote, velocity,  MIDIchannel ); 
#endif

#ifdef MIDI5Pin
          midiSend(( 0x80 | MIDIchannel), activeNote, 0); // send Note Off message for previous note (legato)
#endif          
#ifdef ESP32_BLE_MIDI
          BLEMidiServer.noteOff(  MIDIchannel, activeNote, 0  );
#endif
#ifdef BLE_MIDI
          MIDI.sendNoteOff( activeNote, 0,  MIDIchannel );          
#endif
          activeNote=fingeredNote;
        }
      }
    }
    display_changed= true;  
  }
  lastFingering=fingeredNote; 
}
//_______________________________________________________________________________________________ FUNCTIONS
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

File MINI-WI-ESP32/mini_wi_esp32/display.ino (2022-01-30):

// Funktions for the Display SSD1306
#include <Adafruit_GFX.h>
#include <Adafruit_SSD1306.h>


#define SCREEN_WIDTH 128 // OLED display width, in pixels
#define SCREEN_HEIGHT 64 // OLED display height, in pixels

// Declaration for an SSD1306 display connected to I2C (SDA, SCL pins)
// The pins for I2C are defined by the Wire-library. 
// On an arduino UNO:       A4(SDA), A5(SCL)
// On an arduino MEGA 2560: 20(SDA), 21(SCL)
// On an arduino LEONARDO:   2(SDA),  3(SCL), ...

#define OLED_RESET     4 // Reset pin # (or -1 if sharing Arduino reset pin)
#define SCREEN_ADDRESS 0x3C ///< See datasheet for Address; 0x3D for 128x64, 0x3C for 128x32
Adafruit_SSD1306 display(SCREEN_WIDTH, SCREEN_HEIGHT, &I2Ctwo, -1 );

void display_setup(){
    // SSD1306_SWITCHCAPVCC = generate display voltage from 3.3V internally
  if(!display.begin(SSD1306_SWITCHCAPVCC, SCREEN_ADDRESS)) {
    Serial.println(F("SSD1306 allocation failed"));
    for(;;); // Don't proceed, loop forever
  }

  // Show initial display buffer contents on the screen --
  // the library initializes this with an Adafruit splash screen.
  display.display();
  delay(2000); // Pause for 2 seconds

  // Clear the buffer
  display.clearDisplay();
  display_calibration();

}

/*
char d_line0[40];
char d_line1[40];
char d_line2[40];
char d_line3[40];
char d_line4[40];
char d_line5[40];
*/

// 1 Note
// 2 Oktave
// Pitchbend als Balken?
// Breath-CC als Balken + CC-Number?
// Current Menu

void display_calibration(){
  display.clearDisplay();

  display.setTextSize(2);             // Normal 1:1 pixel scale
  display.setTextColor(SSD1306_WHITE);        // Draw white text
  display.setCursor(0,0);             // Start at top-left corner
  display.println(F( d_line0 ) );
  display.setTextSize(1); 
  display.setCursor(0,25);             // Start at top-left corner
  display.println(F( "Calibration" ) );

  /*display.setTextSize(1);             // Normal 1:1 pixel scale
  display.setCursor(0,30);             // Start at top-left corner
  display.println(F( d_line2 ) );

  display.setCursor(0,40);             // Start at top-left corner
  display.println(F( d_line3 ) );
  */
 // display.setCursor(0,50);             // Start at top-left corner
 // display.println(F( d_line4 ) );

 // display.setCursor(0,60);             // Start at top-left corner
 // display.println(F( d_line5 ) );

/*
  display.setTextColor(SSD1306_BLACK, SSD1306_WHITE); // Draw 'inverse' text
  display.println(3.141592);

  display.setTextSize(2);             // Draw 2X-scale text
  display.setTextColor(SSD1306_WHITE);
  display.print(F("0x")); display.println(0xDEADBEEF, HEX);
*/
  display.display();
  delay(1);
}

// Normal Refresh while playing
void update_display(){
  display.clearDisplay();
  // int num = (pressureSensor);
  if( modus == 0 ){
    display.setTextSize( 1 );             // Normal 1:1 pixel scale
    display.setTextColor(SSD1306_WHITE);        // Draw white text
    display.setCursor( 0, 0 );             // Start at top-left corner
    display.println( d_line0 );
  
    display.setTextSize( 2 ); 
    display.setCursor( 0, 12 );    
    byte octave = fingeredNote / 12;
    byte noteInOctave = fingeredNote % 12;   
    display.setCursor( 20, 12 );    
    display.println( noteNames[noteInOctave] );
    
    display.setTextSize(1);
    display.print( "Oct/Note: ");
    display.setCursor( 2,13 );    
    display.print( octave + 1 );
  
    display.setCursor( 0, 40 );             // Start at top-left corner
    display.println( "PB" );
    display.setCursor( 15, 40 );             // Start at top-left corner
    display.println( touchPin_Value_midi );
       
    display.setCursor( 60, 20 );             // Start at top-left corner
    display.println( "Breath" );    
    display.setCursor( 102, 20 );             // Start at top-left corner
    display.println( ( pressureSensor - breath_Thr ) ); 
    // Draw a Rectangle in the range of breath_max, breath_Thr with the value of pressureSensor
    // 64 Pixels
    int i = (int) round( 64.0 / ( breath_max  - breath_Thr ) * ( pressureSensor - breath_Thr ));
    if(i <1 ) i=1;
    display.fillRoundRect( 64,0, i, 6,  2, SSD1306_WHITE);
    // is connected: isConnected
    if( isConnected==true ){
      display.setCursor( 60, 9 );
      display.println( "BLE conn" );
    }else{
      display.setCursor( 60, 9 );
      display.println( "no BLE !!" );
    }
    

    
    display.setCursor( 60, 30 );             // Start at top-left corner
    display.println( "Finger" );
    display.setCursor( 102, 30 );             // Start at top-left corner
    display.println( lastTouchValue );
    
    display.setCursor( 60, 40 ); 
    display.println( "Touch" );
    display.setCursor( 98, 40 ); 
    display.println( touchPin_Value );
  
    display.setCursor( 0, 50 ); 
    display.println( gyro_total );
  }
 if( modus == 1 ){
    display.setTextSize( 2 );             // Normal 1:1 pixel scale
    display.setTextColor(SSD1306_WHITE);        // Draw white text
    display.setCursor( 0, 0 );             // Start at top-left corner
    display.println( "Menu 1" );
 }
 if( modus == 2 ){

    display.setTextSize( 2 );             // Normal 1:1 pixel scale
    display.setTextColor(SSD1306_WHITE);        // Draw white text
    display.setCursor( 0, 0 );             // Start at top-left corner
    display.println( "Menu 2" );
 }
   
  display.display();
}  

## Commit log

2022-01-04 Create mini-wi-esp32.scad
    Openscad-Script to create Mouthpiece and other needed pieces
    [mini-wi-esp32.scad]
2022-01-27 Create mini_wi_esp32.ino
    Compile the file in the Arduino IDE
2022-01-27 Create MIDI.ino
    More or less a dummy-file. THe MIDI-Lib did not work well together with the BLE-Libs
    [MIDI.ino]
2022-01-27 Create display.ino
    File for updating a SD1306 OLED Display, 128x64 I2C !
2022-01-27 Create mpu6050.ino
    Extra Fille with the functions to read the data from UMP6050 ... did not work well in this project.
    [mpu6050.ino]
2022-01-31 Add files via upload
    Schematic, Wiring-Diagram
2022-01-31 Add files via upload
    Wiring
